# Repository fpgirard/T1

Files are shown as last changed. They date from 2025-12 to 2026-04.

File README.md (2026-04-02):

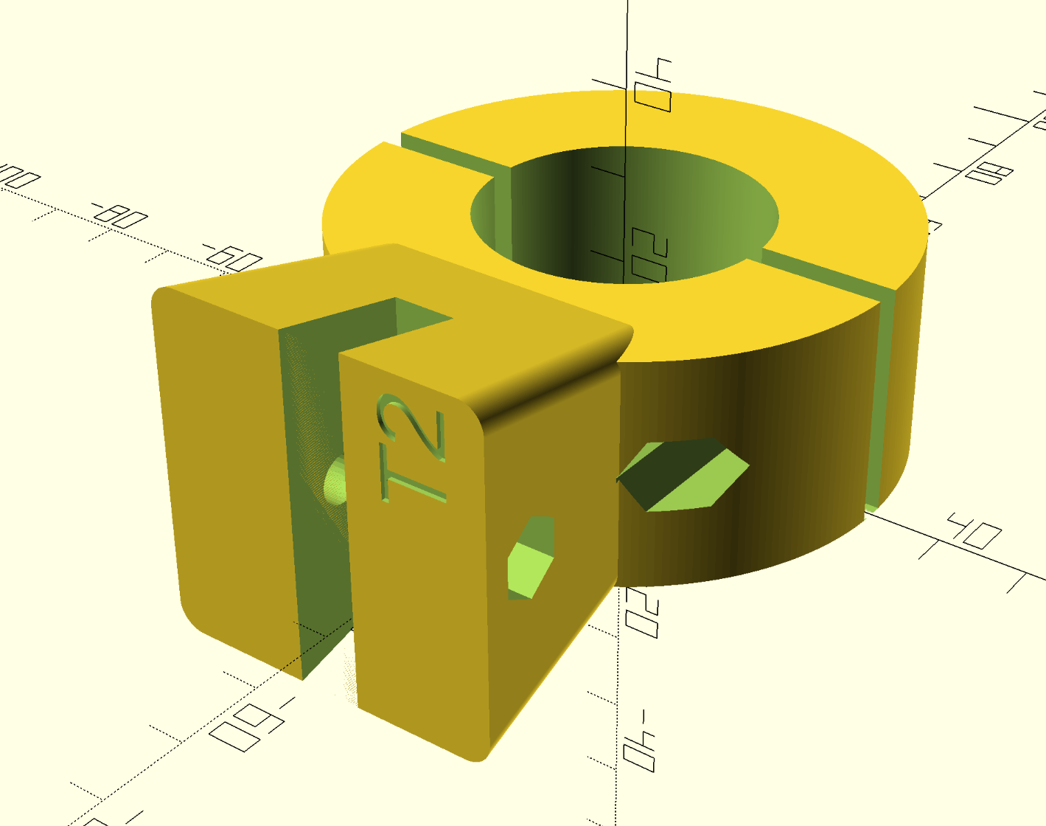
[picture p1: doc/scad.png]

# Aqara T1 Valve Controller Mount

The [Aqara T1 Valve Controller](https://us.aqara.com/products/valve-controller-t1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) is an affordable motorized water shutoff valve whose [mounting bracket](https://us.aqara.com/cdn/shop/files/AqaraValveControllerT1_20.webp?v=1732710054&width=1200) is widely regarded as its weakest component. [Many Amazon reviewers](https://www.amazon.com/gp/customer-reviews/R2XOU6VDMNO59K/ref=cm_cr_dp_d_rvw_ttl?ie=UTF8) cite the included bracket as the device’s Achilles heel, while [users in the Reddit r/Aqara community](https://www.reddit.com/r/Aqara/comments/1lyy8m7/any_tips_on_securing_the_t1_valve_controller/) as well as [Aqara forums](https://forum.aqara.com/t/aqara-water-valve-t1-mounting-brackets/63853/2) frequently discuss the need for a more robust mount design. Details regarding the T1 can be found [here](https://smarthomescene.com/reviews/aqara-t1-water-gas-valve-controller-review/).

The [Tuya Valve Control](https://www.amazon.com/Motorized-Watering-Electric-Controller-Automatically/dp/B0851DYWBH) has a mount that is eerily similar to the Aqara. Buyers report that this product has a solid design with the exception of the metal mounting bracket. Why not create a mount that can be used for both products? [I did](doc/tuya.png).  Next might be the [Dome Water Main Shut-Off valve](https://www.wink.com/products/leak-protection-kit/) which appears to have the same body bracket.  There's a series of comments about the Dome and similar products [suffer the same mount concerns as the Aqara and Tuya](https://community.smartthings.com/t/whats-the-consensus-on-water-valves/87777/7).

Rigorous tests for both using a Home Assistant script that opens and closes these valves at random intervals between 1 and 3 minutes would be a logical next step.  Let's see which one dies first.  Perhaps I should add the Bulldog to the mix?

This project provides the Aqara and Tuya controllers with a sturdy mount that:

1. Attaches to the valve body and not the pipe.  This is consistent with [plumbing best practices](https://m.media-amazon.com/images/I/61tk9mOD39L._AC_SL1200_.jpg).  
2. Incorporates a C-clamp design that mitigates twisting during operation.  This is even more foolproof and customizable than the one offered on [the EcoNet Bulldog](https://m.media-amazon.com/images/I/61tk9mOD39L._AC_SL1200_.jpg).    
3. Fits a [large variety of valves](doc/valves.jpg). 
4. Brings the Zigbee-based Aqara and Tuya controllers on par with the Z-Wave-based [EcoNet Bulldog](https://www.amazon.com/EcoNet-Controls-EVC200-HCSML-Friendly-Plumbing/dp/B07DJZCFBH) at one-third the price.

This repository has the following directories:

[<code>src</code>](https://github.com/fpgirard/Aqara-Tuya/tree/main/src) has OpenSCAD source for the T1 mount and HA test scripts for 100 on/off tests  
[<code>stl</code>](https://github.com/fpgirard/Aqara-Tuya/tree/main/stl) contains various .stl files for different valve bodies for both the Aqara and Tuya controllers   
[<code>doc</code>](https://github.com/fpgirard/Aqara-Tuya/tree/main/doc) has installation instructions and other supporting documents (images).

Current valves supported for this project are the Sharkbite 3/4" valves (old and new) and the Watts 3/4" LFFBV-3C-M1 but if [we follow EcoNet](https://cdn.shopify.com/s/files/1/0929/0448/9329/files/Alternate-Kits-01_1.jpg), the following alternate mounting brackets might be next:

* HC2XXL Mounting Kit for Large Valves
* 3/4” Propress Mounting Kit for ¾” Propress Valves
* 1” Propress Mounting Kit for 1” Propress Valves
* 1-1/4” Propress Mounting Kit for 1-1/4” Propress Valves
* 1-1/2” Propress Mounting Kit for 1-1/2” Propress Valves
* HC3PEX0.5 Mounting Kit for Pex B 1/2" Tab Ring Valves
* HC3PEX0.75 Mounting Kit for Pex B 3/4" Tab Ring Valves
* HC3PEX1 Mounting Kit for Pex B 1" Tab Ring Valves
* Other - Send your valve body measurements, a photo, and manufacturer’s make and model information to [fpgirard@gmail.com](mailto:fpgirard@gmail.com).  

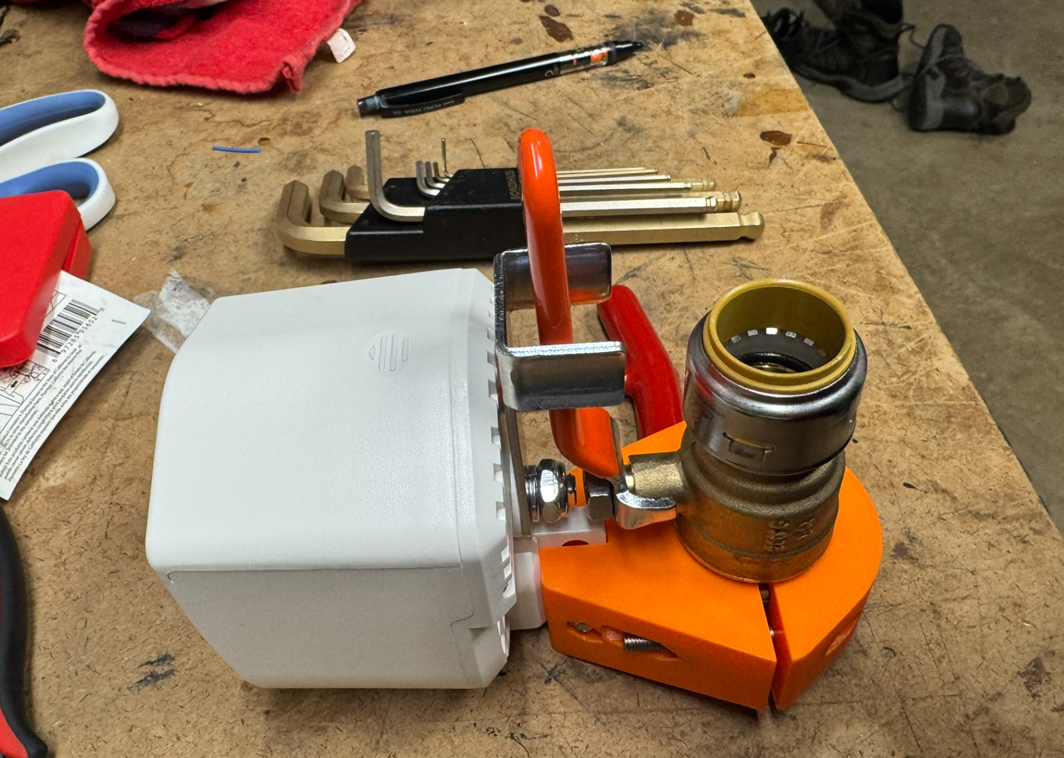
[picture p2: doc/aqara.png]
Aqara controller

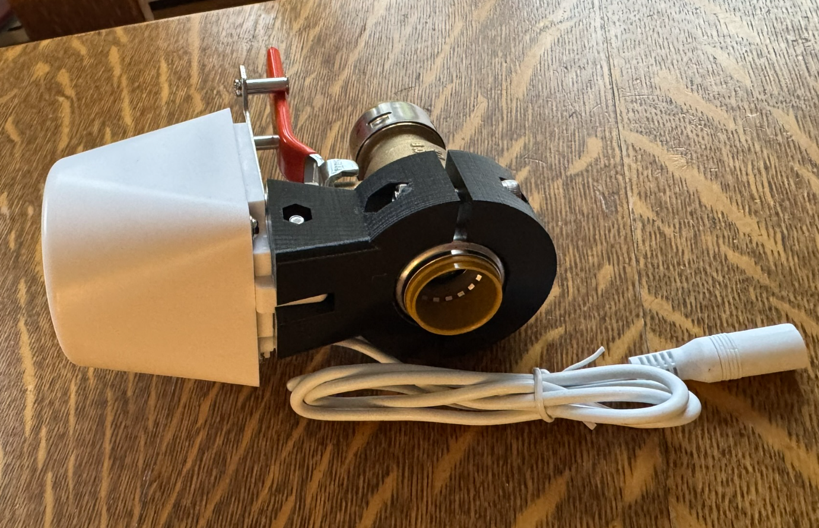
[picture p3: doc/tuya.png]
Tuya controller


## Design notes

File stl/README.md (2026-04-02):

##Notes

1. The Watts 3/4" LFFBV-3C-M1 valve's shutoff lever is reversible. Reverse this lever and use the fixed nut to secure the mount.

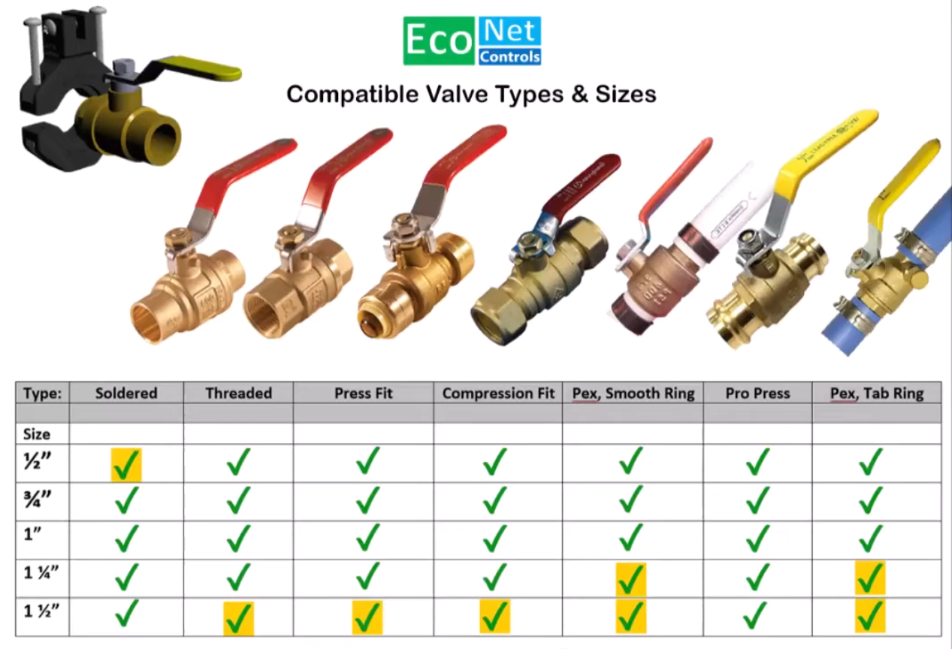
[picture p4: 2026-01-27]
doc/bulldog-valves.png

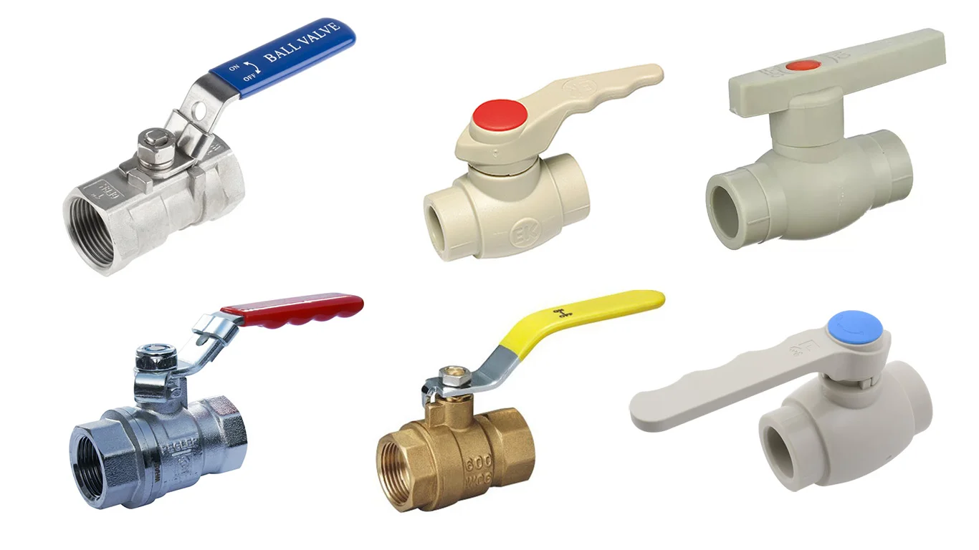
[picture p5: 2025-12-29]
doc/valves.jpg

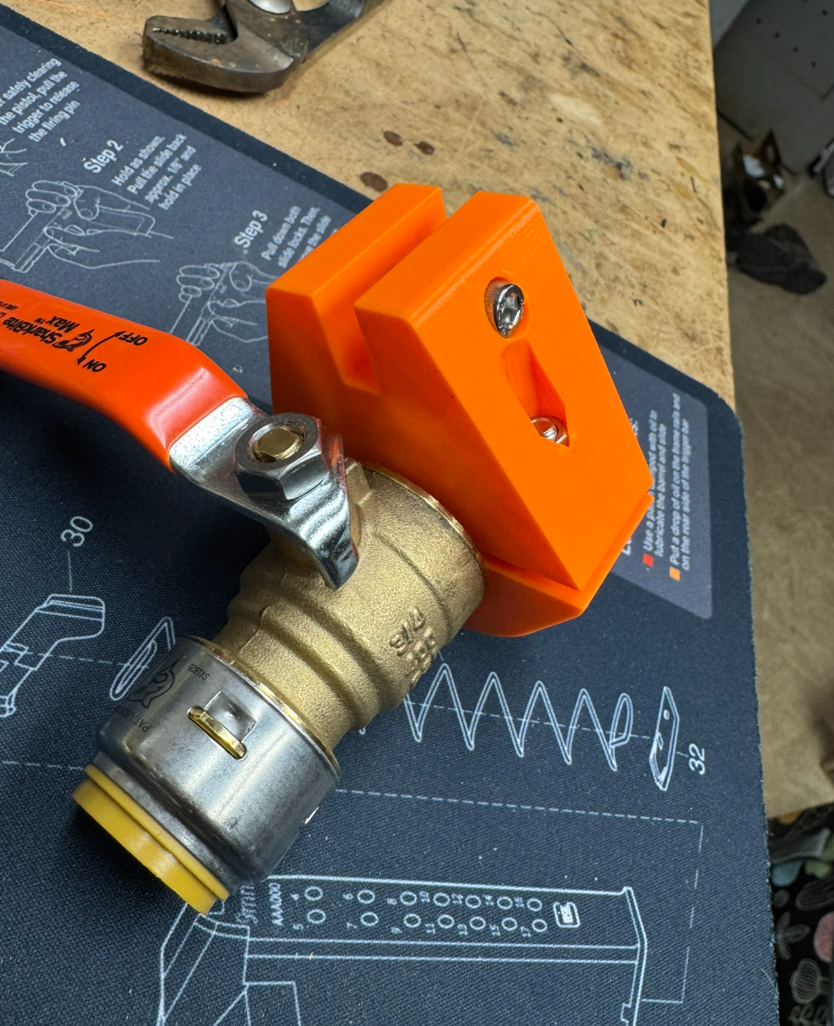
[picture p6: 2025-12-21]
doc/side.png

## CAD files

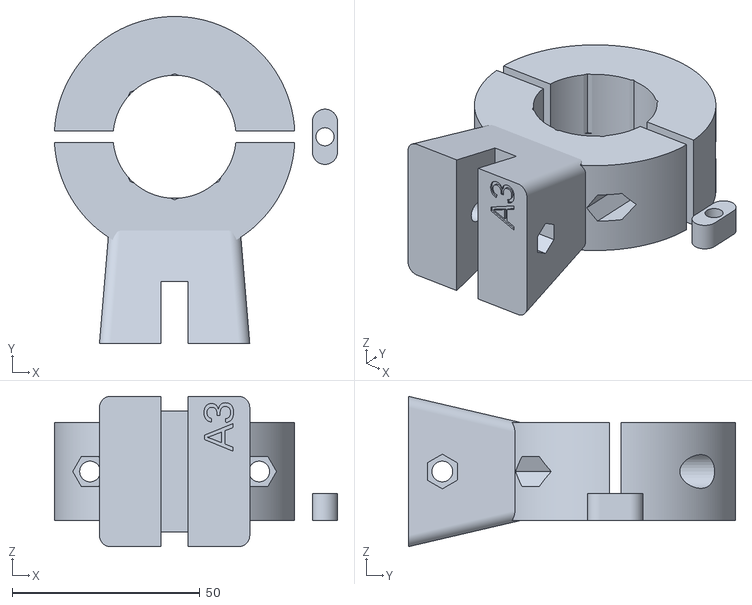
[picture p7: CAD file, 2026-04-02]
stl/A3.stl
75.3 x 87.0 x 40.0

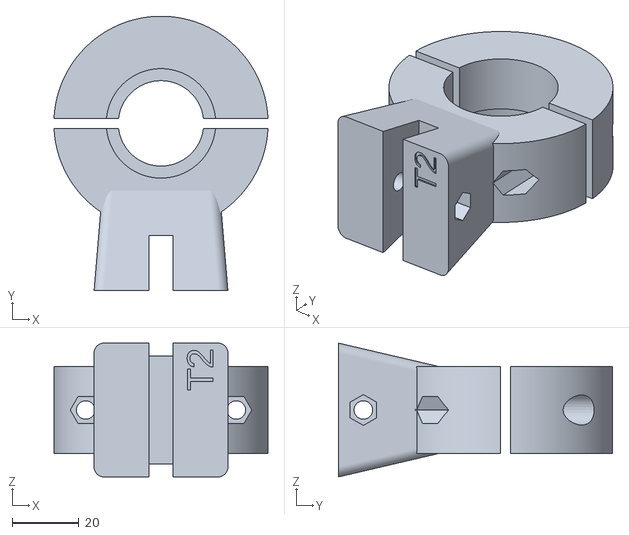
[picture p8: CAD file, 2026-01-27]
stl/T2.stl
63.9 x 82.0 x 40.0

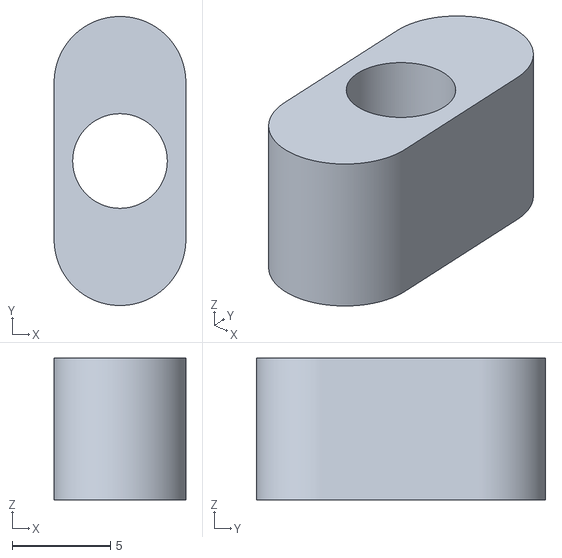
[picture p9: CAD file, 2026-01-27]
stl/washer.stl
6.70 x 14.7 x 7.20

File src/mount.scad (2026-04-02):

include <BOSL2/std.scad>
include <BOSL2/screws.scad>
$fn=256;

// Aqara T1 Shutoff Valve

ih1 = 6; ih2 = 20;
d1 = 0; d2 = 0; d3 = 0;
oh = ih1 + ih2; od = 64;
model = "X";
ch = 43;
aqara_h = 33; aqara_w = 7.2; aqara_d = 16.5;
washer_od = 6.7; washer_id = 4.81;
wrench = 31;

module mirror2(v) {
    children();
    mirror(v) children();
}
// Modules for different valve fittings
module cutout(model,tuya,d1,d2,d3) { // cutouts for the inner valve type
     cylinder(d=d1,h=ih1);   //ring
     translate([0,0,ih1]) cylinder(d=d3,h=3.5); //lip
     translate([0,0,ih1]) cylinder(d1=d2,d2=d2,h=ih2+10); // clamp base
     bolt_offset = tuya ? -47.5 : -46;    // Tuya bolt height, Aqara bolt height
     translate ([0,bolt_offset,13]) rotate([0,-90,0]) screw_hole("M5,35",head="socket",counterbore=8, $fn=32, $slop=0.0) position(BOT) nut_trap_inline(10);  // controller bolt
     translate([8,-54.5,25]) rotate([0,-90,90]){ linear_extrude(.75) text(model, size=8, valign="top", halign="center",direction="ltr"); } // demarcation   
}
module base() {
  difference() {
     union() { 
         cylinder(d=od,h=oh);  // main body
         translate([0,-25,13]) rotate([90,0,0]) prismoid(size1=[35,oh], size2=[40,40], h=30, rounding=3);  
     }
     //cutout(model="A1", tuya=false, d1=25.5, d2=32.7,d3=d2);    // Aqara (A) with original sharkbite (1)
     //cutout(model="T1", tuya=true, d1=25.5, d2=32.7, d3=d2);     // Tuya (T) with original sharkbite (1)
     //cutout(model="A2", tuya=false, d1=25.5, d2=32.7,d3=d2);    // Aqara (A) with new sharkbite (2)
     //cutout(model="T2", tuya=true, d1=25.5, d2=32.7, d3=33.5);   // Tuya (T) with new sharkbite (2)
     cutout(model="A3", tuya=false, d1=32.7, d2=32.7, d3=d2); translate([0,0,8]) rotate([0,0,90]) linear_sweep(octagon(id = wrench), h = 20); // Aqara with WATTS (W) LFFBV-3C-M1
     //cutout(model="T3", tuya=true, d1=32.7, d2=32.7, d3=d2); translate([0,0,8]) rotate([0,0,90]) linear_sweep(octagon(id = wrench), h = 20); // Tuya with WATTS (W) LFFBV-3C-M1
     
     // cutouts common across all valve types
     mirror2 ([1,0,0]) translate([22.5,0,oh/2]) rotate([-90,0,0]) screw_hole("M5,40",head="socket",counterbore=14, $fn=32, $slop=0.0) position(BOT) nut_trap_inline(18);  // pipe bolts
     translate([-40,-1.5,0]) cube([80,3,40]); // collar slit
     translate([-aqara_w/2,-55,-10]) cube([aqara_w,aqara_d,aqara_h+20]); // controller slot
  }    
}
module washer() {
   difference() { 
       hull() { mirror2([0,1,0]) translate([0,4,0]) cylinder(d=washer_od, h=aqara_w); }
       cylinder(d=washer_id, h=aqara_w);
   }
} 

base();  // mount
translate ([40,0,0])washer();

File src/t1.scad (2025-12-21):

include <BOSL2/std.scad>
include <BOSL2/screws.scad>
$fn=128;

// Mount offset 
ih1 = 6; ih2 = 20;
oh = ih1 + ih2; od = 60;
ch = 33;
aqara_h = 33; aqara_w = 7.2; aqara_d = 16.5;
washer_od = 6.7; washer_id = 4.81;

// example usage: mirror2 ([1,0,0]) translate ([35,0,0]) mounts();

module mirror2(v) {
    children();
    mirror(v) children();
}

// These are the various modules used for different valve fittings
module shark() {
     d1 = 25.5; d2 = 32.25; d3 = d2;
     cylinder(d=d1,h=ih1);   //ring
     translate([0,0,ih1]) cylinder(d1=d2,d2=d2,h=ih2+10); // clamp base
}
module newshark() {
     d1 = 25.5; d2 = 32.7; d3 = 33.5;
     cylinder(d=d1,h=ih1);   //ring
     translate([0,0,ih1]) cylinder(d=d3,h=3.5); //lip
     translate([0,0,ih1]) cylinder(d1=d2,d2=d2,h=ih2+10); // clamp base
}

module base() {
  difference() {
     hull() { 
         mirror2 ([1,0,0]) translate ([26,0,0]) cylinder(d=18,h=oh);
         cylinder(d=od,h=oh);
         translate([0,-30,ch/2]) cuboid([30,40,ch], rounding=3, edges="Z");
     }
     shark();    // shark(), newshark(), other mounting sizes modules go here.
     mirror2 ([1,0,0]) translate([22.5,-7,oh/2]) rotate([90,0,0]) screw_hole("M5,45",head="socket",counterbore=15, $fn=32, $slop=0.0) position(BOT) nut_trap_inline(15);  // pipe bolt holes
     translate ([0,-41,ch/2]) rotate([0,90,0]) screw_hole("M5,35",head="socket",counterbore=8, $fn=32, $slop=0.0) position(BOT) nut_trap_inline(10);  // aqara bolt holes
     translate([-40,-1.5,0]) cube([80,3,40]); // pipe opening
     translate([-aqara_w/2,-50,0]) cube([aqara_w,aqara_d,aqara_h]);
  }    
}
module washer() {
   difference() { 
       hull() { mirror2([0,1,0]) translate([0,4,0]) cylinder(d=washer_od, h=aqara_w); }
       cylinder(d=washer_id, h=aqara_w);
   }
} 

base();  // Pipe mount
translate ([40,0,0])washer();

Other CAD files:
stl/T3.stl
stl/A2.stl

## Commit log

2025-12-29 Incorporated the Tuya valve controller
    The Aqara and Tuya mounts are eerily similar - why not have mounts for both?
    [mount.scad, shark.stl, washer.stl]
2025-12-31 Reversed controller bolt
    and README cleanup
    [mount.scad]
2026-01-27 clean up before public
    [A2.stl, T2.stl, mount.scad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]
2026-04-02 Added Watts Valve
    [A3.stl, T3.stl, mount.scad]
2026-04-02 Candidate Wyatt Valves
    [A3.stl, T3.stl, mount.scad]
